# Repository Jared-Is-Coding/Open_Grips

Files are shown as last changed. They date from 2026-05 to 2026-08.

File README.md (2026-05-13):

Open Grips – Isolated Frictionless Ergonomic Grip Training for FDP and FDS

## Original Project

The original project uses FreeCad for parametric modeling, and 3D printing for manufacturing. See PDF for full description

## This Fork

The key things I was aiming to improve in this fork were:

### Standard file format

The FreeCAD file format exports were not easy to move between programs for modification. My hope is that by providing a .step file users in the future will be able to open and modify the file to their liking in whatever CAD software they use.

### Ease of printing

The original models were not set up for efficient FDM printing. Through the addition of new angled walls and the adjustment of other areas, the prints are now all sufficiently set up for FDM printing with no supports needed.

- The Sisyphus model has been completely redesigned to take on the style of the Prometheus model in terms of assembly and style, allowing simpler printing *and* assembly
- The pins may now be printed
- The pins may be printed horizontally for strength and reduced failures
- The long, structural pin may also be printed horizontally for strength and reduced failures
- The frame pieces may now be printed sideways, without supports
- The chamfers and fillets on both tools have been generally improved for FDM printing

### Additional guard top piece

I've added a top piece to be printed in TPU as a guard for the tools.

### Documentation

You're reading it! There's more work to be done, but the process of modifying the print files still needs some work.

### Simple file modification for each user

One of the core ideas advertised by a company out there is that each user's hand is a little different and requires minute adjustments to get things just right for each person. In practice, we've found this to be not majorly important (exact measurements and adjustments from person to person do not heavily impact the effectiveness of the training), but for major differences in hand/finger sizes it is definitely still relevant.

In the original models, this modification was done using parametric model variables. I wasn't very familiar with FreeCAD, so in moving over to Fusion360 I dropped the compatibility with these variables. I plan to work on reimplementing them as I'm able. (Unless someone else wants to? :) For now, modification will need to be done by hand.

Until I finish some new tooling for adjusting these files, I'll explain the gist of what we've thought through here:

#### Prometheus

##### Roller Up/Down Offset

The length of the full finger may be used for up/down placement offsets of the rollers. Using the pinky length as "0", you can then calculate the height of the offset of each roller by subtracting the height of the pinky from height of the finger.

So, if your pinky was 60mm:

(Vertical offset of 79mm Ring finger roller pin) = 79mm - 60mm = ~19mm

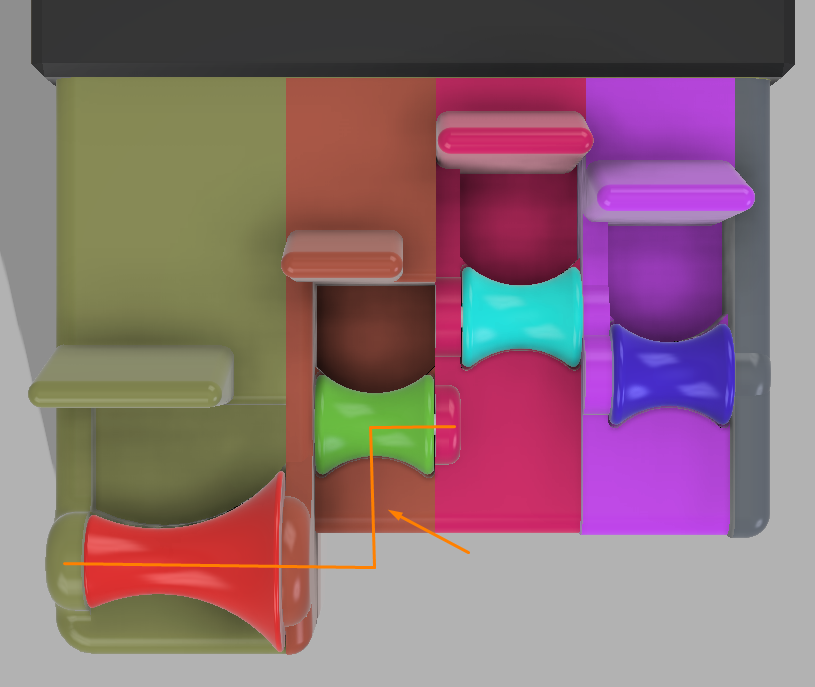
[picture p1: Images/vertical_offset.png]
Vertical offset example


##### Roller Forward/Backward Offset

The length of the PIP joint to the DIP joint ("P->D") may be used for forward/backward offsets of the rollers. Using the pinky length as "0", you can then calculate the offset of each roller by subtracting the length of the pinky P->D from the finger P->D.

So, if your pinky P->D was 18.5mm:

(Horizontal offset of a 27mm Ring finger roller pin) = 27mm - 18.5mm = ~8.5mm

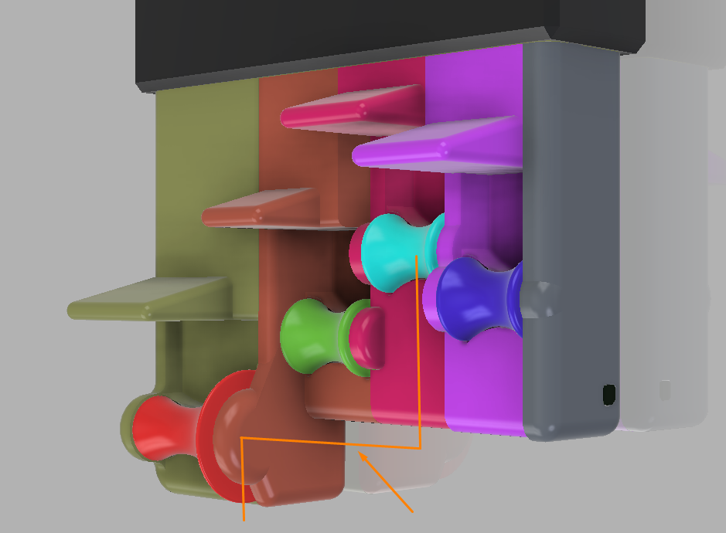
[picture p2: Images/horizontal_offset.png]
Horizontal offset example


##### Roof Height

The length of the DIP joint to the tip of your finger may be used to calculate the height of the roof of each finger roller to achieve an "ideal" angle to maintain.

(Roof Height) = (DIP to Fingertip) / tan(Desired Angle)

Based on our findings, the desired angles are roughly:

Index: 57°
Middle: 60°
Ring: 60°
Pinky: 55°

So, if your Index finger DIP to Fingertip was 28mm:
(Roof Height) = 28 / tan(57) = ~18.18mm

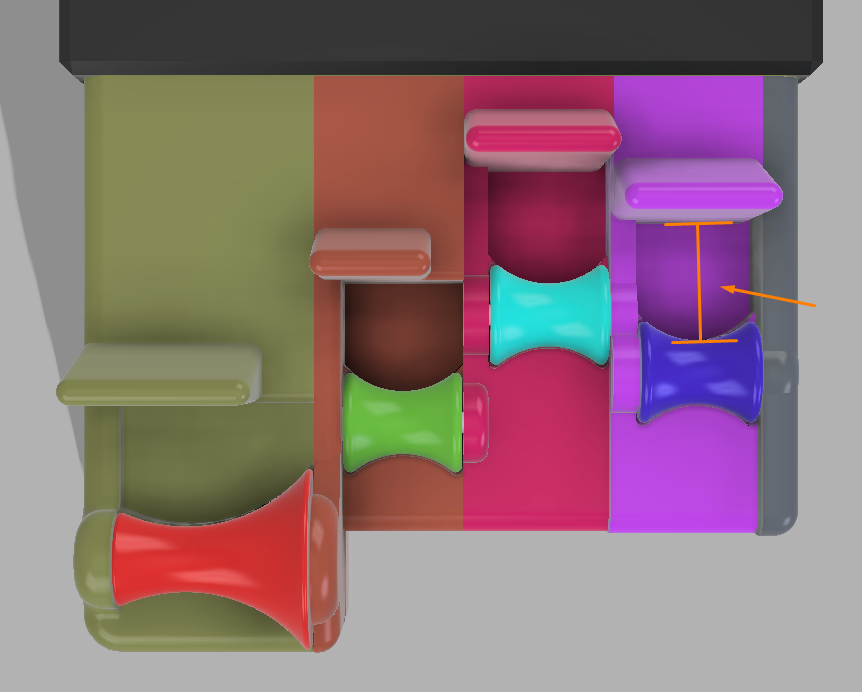
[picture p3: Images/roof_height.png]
Roof height example


#### Sisyphus

##### Roller Offset

See each "Roller Offset" area above. Apply the same concepts.

##### Roller Diameter

TBD

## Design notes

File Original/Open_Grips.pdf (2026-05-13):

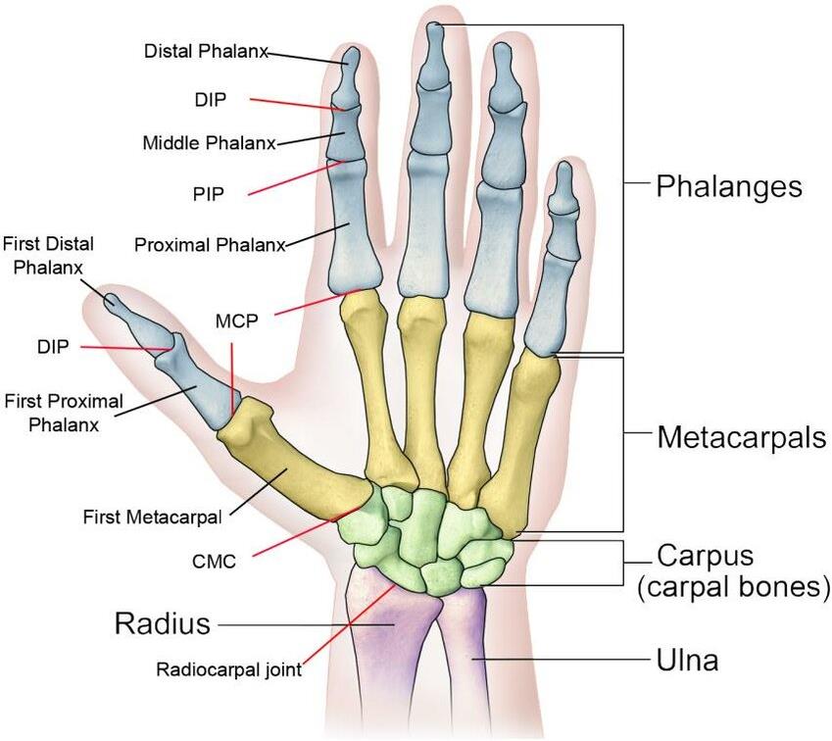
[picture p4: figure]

P a g e 1 | 9

# Open Grips – Isolated Frictionless Ergonomic Grip Training for FDP and FDS

Version 1.1

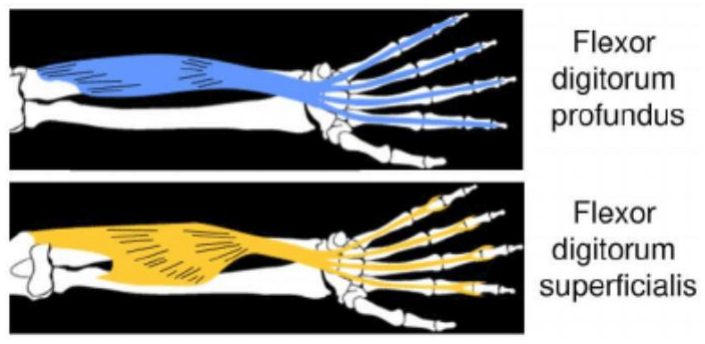
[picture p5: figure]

P a g e 2 | 9

## 1. Overview:

The idea to train FDS and FDP separately using frictionless ergonomic devices to improve climbing performance was first put forward by David Quinn (mobeta) out of Halifax, NS, Canada. The idea being that most climbers will become dominant in one over the other muscle group, thereby not achieving their maximal strength potential. Finger strength on the wall will almost always use a combination of both (as well as other) muscle groups, so by isolating these two in training (as much as possible) it should be probable to see gains in performance strength. The ergonomic side should allow for maximum force exertion without stressing the finger pulleys or causing other types of finger pain like synovitis. Frictionless implementation ensures that active engagement and not passive grip is being

## used throughout the entire exercise (skin friction vs active muscle engagement). While an

oversimplification, the FDP flexes the DIP joint, and the FDS flexes the PIP joint.

The Open Grips project aims to be a free and open-source version for the community to use, experiment, and hopefully improve. It makes no claims to have an optimized solution but does aim for continuous improvement. If you want the original and professionally produced version of these training tools head on over the handofgod shop.

This project uses FreeCad for parametric modeling, and 3D printing for manufacturing.

## 2. FDS: Sisyphus Gripper

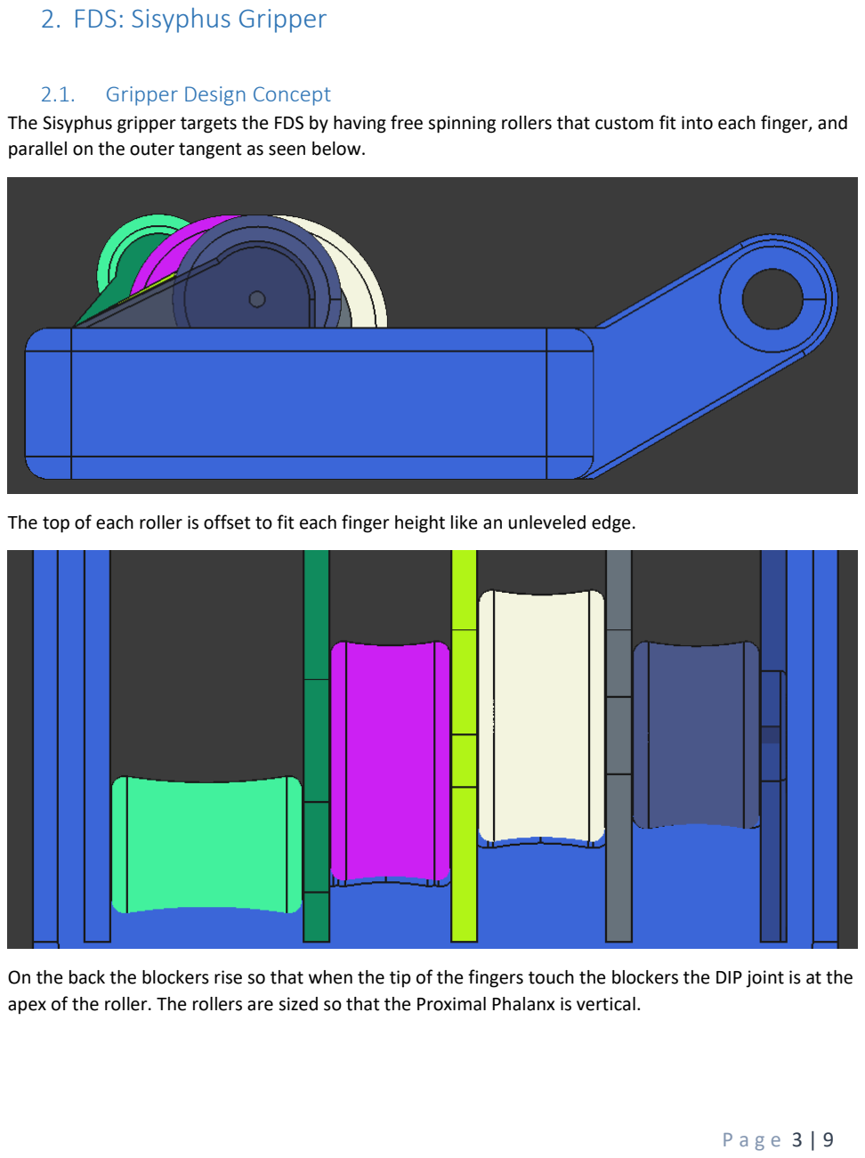
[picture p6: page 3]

P a g e 3 | 9

### 2.1. Gripper Design Concept

The Sisyphus gripper targets the FDS by having free spinning rollers that custom fit into each finger, and parallel on the outer tangent as seen below.

The top of each roller is offset to fit each finger height like an unleveled edge.

On the back the blockers rise so that when the tip of the fingers touch the blockers the DIP joint is at the apex of the roller. The rollers are sized so that the Proximal Phalanx is vertical.

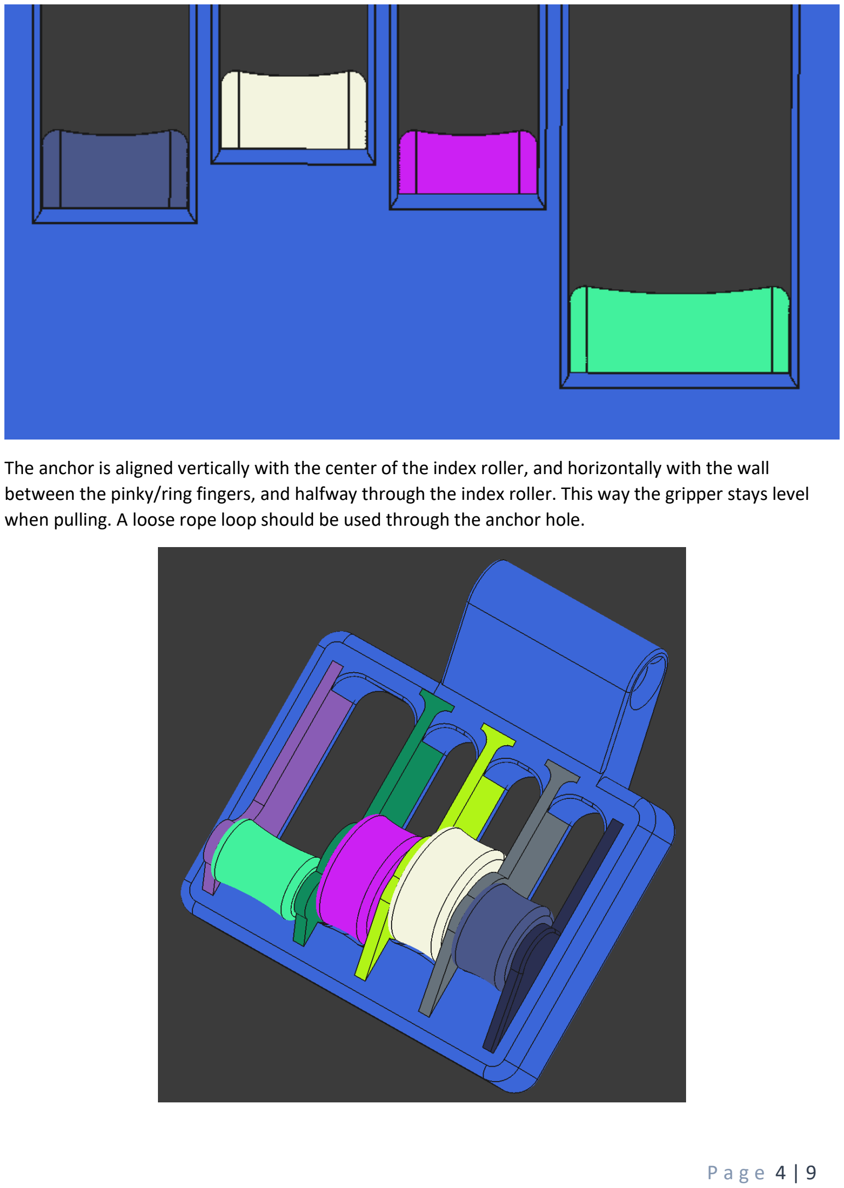
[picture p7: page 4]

P a g e 4 | 9

The anchor is aligned vertically with the center of the index roller, and horizontally with the wall between the pinky/ring fingers, and halfway through the index roller. This way the gripper stays level when pulling. A loose rope loop should be used through the anchor hole.

P a g e 5 | 9

### 2.2. Gripper Assembly

Walls roller and frame are all printed separately then walls and rollers are assembled as seen below and then lowered into the frame. A pole for the rollers should be of metal. A 3mm nail was cut and used in the prototype. Make sure not to make the pole to long or it will puncture the walls on assembly. If printed without scaling down the walls should fit tightly. They can be tamped down by hammer with a block of wood across the tops of the walls.

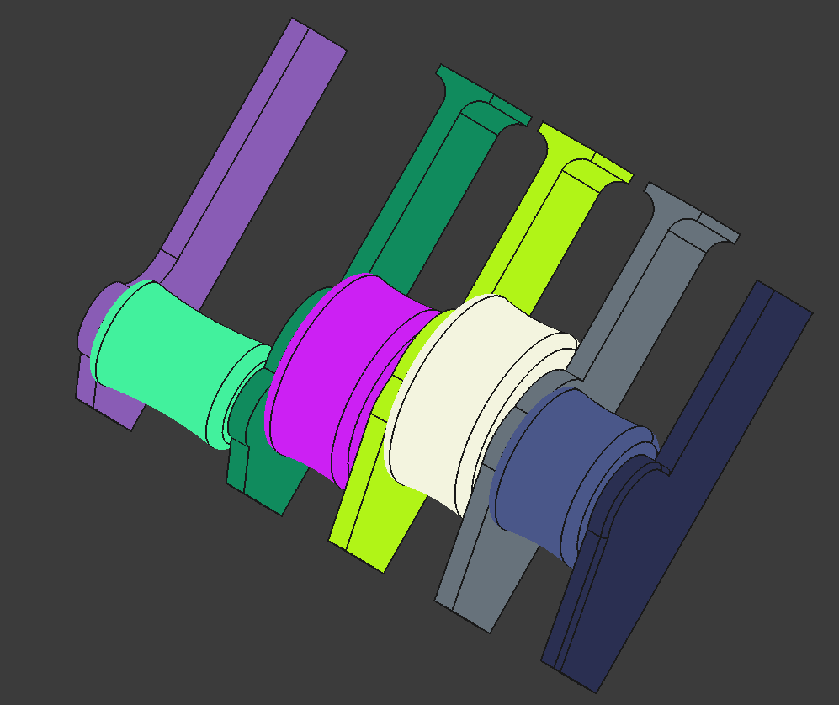
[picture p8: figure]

### 2.3. Measurement Variables

Four variables for each finger replace X with (I=index, M=middle, R=Ring, P=Pinky)

Frame_Height | Inside Height of the frame, adjust if not enough space above fingers
Pole_Width | Diameter of the metal roller poles
Wall_Width | Width of internal wall. Best not to change, 4mm seems very strong.
X_Height | Height from the bottom of the pinky to the bottom of the finger. P_Height is always zero.
X_Diameter | Diameter of each fingers roller
X_Width | Width of each fingers roller
X_Blocker | Height from the center of the roller to the top of the fingers blocker. For the Pinky this is below the center of the roller instead.

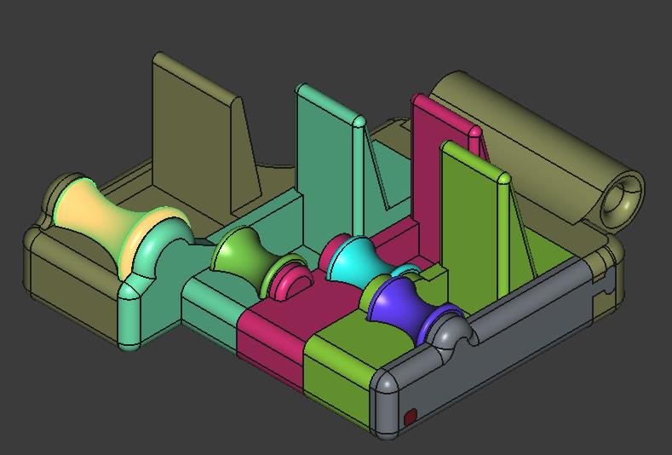
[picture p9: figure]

P a g e 6 | 9

## 3. Design – FDP: Prometheus Gripper

### 3.1. Gripper Structure

The Prometheus gripper targets the FDP by placing all the force on the end of the distal phalanx in a claw like grip. Imagine you form your hand to hold a thin jug but only the tips of your fingers are making contact. Your PIP and DIP joints are flexed about 55 Deg each and proximal phalanx is once again vertical. For this to be the case for each finger the height and depth of each roller must be set.

The blockers above the rollers should be touched by the DIP joint and keep the grip from becoming a crimp. The rollers have a ledge in front so roughly half a pad is making contact, quarter on the roller, quarter on the ledge.

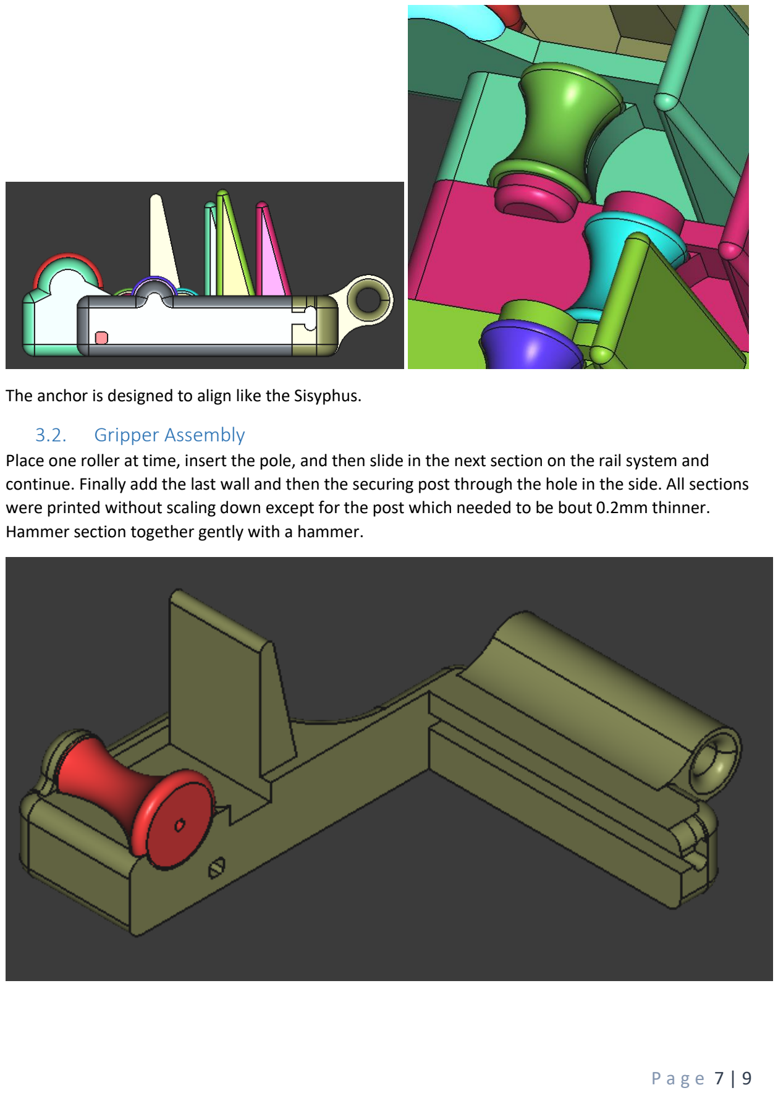
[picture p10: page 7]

P a g e 7 | 9

The anchor is designed to align like the Sisyphus.

### 3.2. Gripper Assembly

Place one roller at time, insert the pole, and then slide in the next section on the rail system and continue. Finally add the last wall and then the securing post through the hole in the side. All sections were printed without scaling down except for the post which needed to be bout 0.2mm thinner. Hammer section together gently with a hammer.

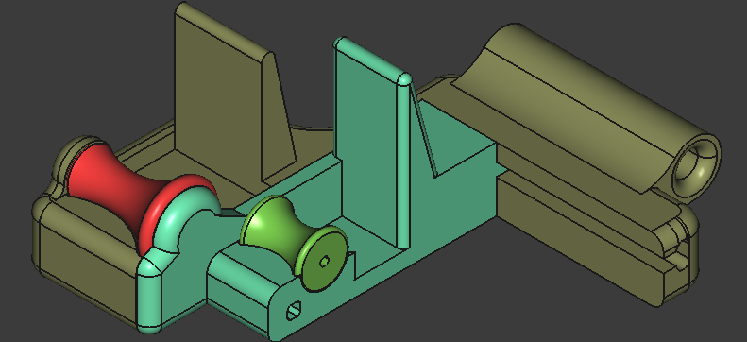
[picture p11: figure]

P a g e 8 | 9

### 3.3. Measurement Variables

Five variables for each finger replace X with (I=index, M=middle, R=Ring, P=Pinky). Change these as needed in VarSet.

Blocker_Height | Height of blocker, shouldn’t need to change
Pole_Diameter | Diameter of the metal roller poles
Wall_Width | Width of internal wall. Best not to change, 4mm seems very strong.
X_Height | Height from the bottom of the pinky to the bottom of the finger. P_Height is always zero.
X_Diameter | Diameter of each fingers roller
X_Width | Width of each fingers roller
X_To_Blocker | Height from the bottom of finger to the bottom of the blocker
X_Depth | How farther in the tip of the finger is when in the claw grip from the pinky. P_Depth is always zero.

P a g e 9 | 9

## 4. Printer Settings

- Filament: PETG-HF
- Layer Height: 0.2mm
- Nozzle Size: 0.4mm
- Wall Loops: 5
- Infill: cubic 35%
- Supports: Normal (for frame only)
- Orientation: Rollers on their side. For the Sisyphus print everything as modeled. For the Prometheus print frame and wall on their side with holes pointing up so no supports go inside.

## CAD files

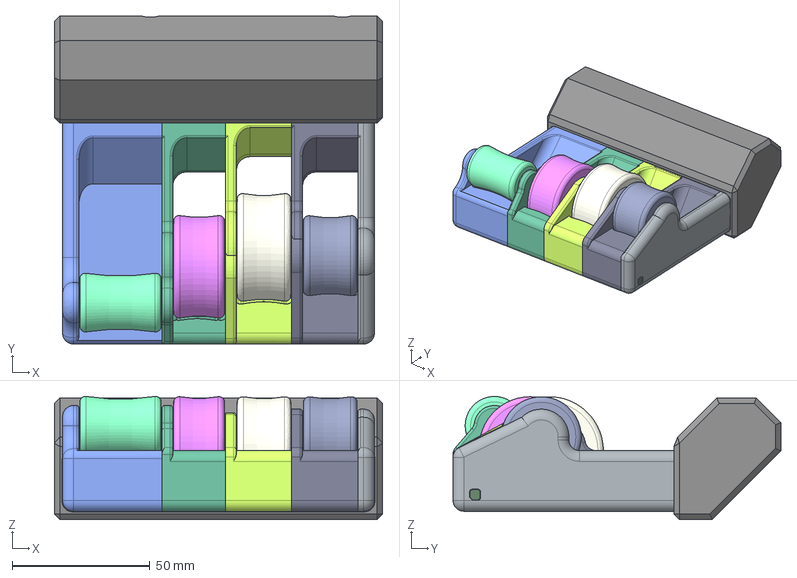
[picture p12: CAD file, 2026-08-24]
OpenGrips Sisyphus v27.step
119.0 x 118.8 x 44.6 mm
Frame
Pinky Roller
Pinky Pin
Ring Wall
Ring Roller
Ring Pin
Middle Wall
Middle Roller
Middle Pin
Index Wall
Index Roller
Index Pin
End Wall
Post
Guard

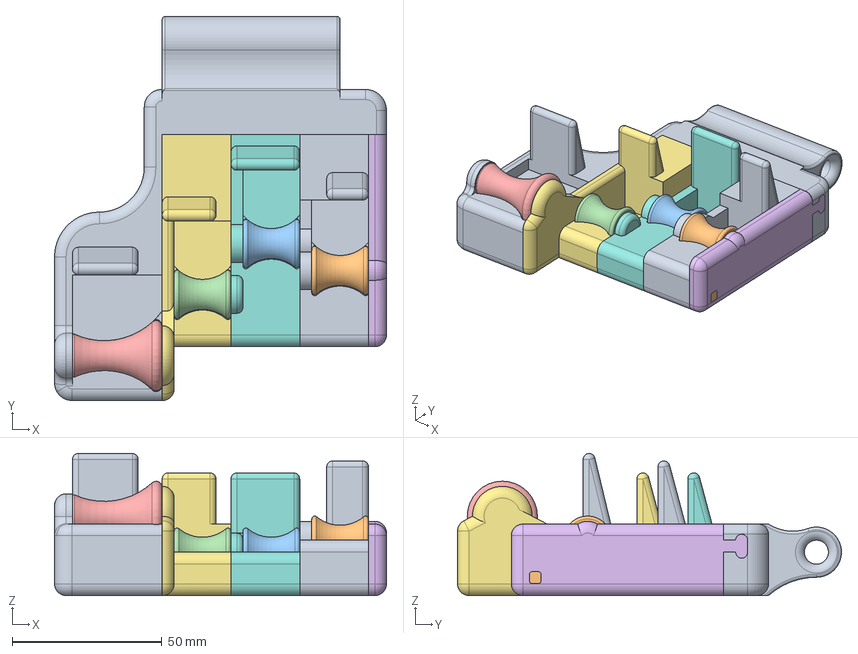
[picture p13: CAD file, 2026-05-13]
Original/OpenGrips_Prometheus.FCStd
111.0 x 128.4 x 47.5 mm
Frame
I_Roller
M_Roller
R_Roller
P_Roller
End_Wall_5
Cut_R_wall
Cut_M_wall
Cut_I_wall
Post

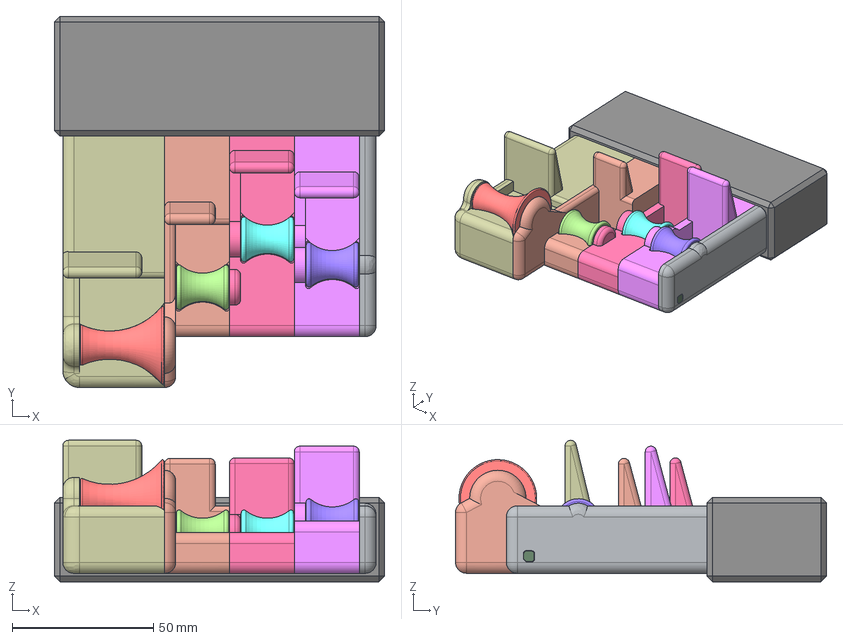
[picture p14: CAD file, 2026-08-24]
OpenGrips Prometheus v43.step
117.0 x 131.4 x 50.1 mm
Frame
Pinky Roller
Pinky Pin
Ring Wall
Ring Roller
Ring Pin
Middle Wall
Middle Roller
Middle Pin
Index Wall
Index Roller
Index Pin
End Wall
Post
Guard

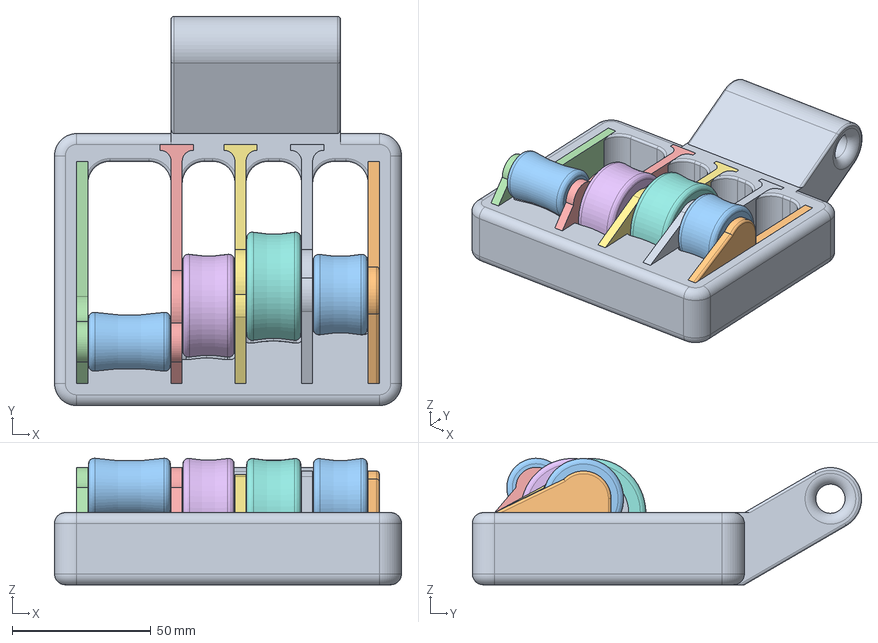
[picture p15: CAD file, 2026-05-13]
Original/OpenGrips_Sisyphus.FCStd
125.0 x 140.2 x 45.6 mm
frame
P_Pole
P_Roller_print
Wall_1_print
Wall_2_print
R_Roller_print
Wall_3_print
M_Roller_print
Wall_4_print
Wall_5_print
I_Roller_print

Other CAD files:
OpenGrips Prometheus V42.step

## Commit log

2026-05-13 Inititalize fork
    [OpenGrips Prometheus V42.step, OpenGrips Sisyphus V25.step, OpenGrips_Prometheus.FCStd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]
2026-08-24 Add latest file versions
    [OpenGrips Prometheus v43.step, OpenGrips Sisyphus V25.step, OpenGrips Sisyphus v27.step]
